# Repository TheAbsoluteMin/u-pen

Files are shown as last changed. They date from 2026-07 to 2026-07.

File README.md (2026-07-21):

# uPen

PCB_1
Case1

uPen is a WiFi-enabled smart pen that records handwritten math equations and solves them.

## Inspiration

Initially, uPen was named Insta-Form, and it would have served as an alternative for Photomath. With its own camera, it would have captured images of math problems during engineering work and then solve them instantly in order to provide a seamless experience when working with mathematical models, physics, or measurement calculations. Before, I would personally spend a lot of time writing out equations and models by hand or on a calculator. Now, uPen seeks to increase productivity and efficiency by bypassing the precious time required to find answers manually. As I have worked extensively on uPen's design and creation, I have changed its physical hardware for it to be more intuitive to use. Instead of taking pictures with a camera, users can write naturally with uPen, and it will still be able to carry out its original and intended purpose of delivering quick math answers at users' convenience!

## How it works

pageONE



## Firmware Upload Instructions

Use Arduino IDE to upload the C++ code to the uPen board (NanoS3 ESP32-S3).

## Battery Wiring Instructions

When you wire the battery with the 28 AWG wire:
1. Solder the NEGATIVE battery wire to the B- pad of the Li-ion BMS Battery Protection.
2. Solder a wire between the P- pad of the Li-ion BMS Battery Protection and the P- testpoint on the PCB.
3. Solder the POSITIVE battery wire to the RawBAT+ testpoint on the PCB.
4. Solder a wire between the B+ testpoint on the PCB to the B+ pad of the Li-ion BMS Battery Protection.
5. Solder a wire between the P+ pad of the Li-ion BMS Battery Protection and the P+ testpoint on the PCB.

## Features

* Uses compact yet powerful dual core ESP32 in the NanoS3 board
* LSM6DSV16X IMU 6-axis sensor fusion
* SDS001R tip switch for fast detection of writing state
* Small but powerful E-Flite 1S 3.7V 150mAh 45C LiPo battery
* External Li-ion BMS battery protection board
* Strong dipole 2.4GHz RX antenna
* Smart power states
* USB-C port for charging and coding
* USBLC6-2SC6 ESD protection
* Low battery alert at 15% battery
* Lightweight wireless data streaming to a base station ESP32 via ESP-NOW
* Dual I2C buses for fast data processing

## Full BOM

> [Full CSV](https://github.com/TheAbsoluteMin/u-pen/blob/main/fabrication/uPen_Full_Parts_BOM_7-21-2026.csv)

* [uPen PCB by JLCPCB](https://github.com/TheAbsoluteMin/u-pen/tree/main/fabrication)
* [NanoS3](https://www.mouser.com/en/ProductDetail/Unexpected-Maker/NS3-01?qs=Z%252BL2brAPG1JKEi5QQZzXXw%3D%3D)
* [E-Flite 1S 3.7V 150mAh 45C LiPo Battery](https://vortexhobbies.com/flite-150mah-37v-45c-lipo-battery-eflb1501s45-p-98338.html)
* [Conn_01x04 Header Pin](https://www.aliexpress.us/item/3256808220037580.html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)
* [0.91 Inch OLED Module](https://www.aliexpress.us/item/3256806851980220.html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)
* [2.4GHz FPC Antenna](https://www.aliexpress.us/item/3256806439437721.html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)
* [Li-ion BMS Battery Protection](https://www.aliexpress.us/item/3256811824864401.html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)
* [Micro JST PH 1.25 2 PIN Male Plug Connector](https://www.aliexpress.us/item/3256806436736526.html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)
* [28 AWG Wire](https://www.aliexpress.us/item/3256801404161291.html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)
* [ESP32-S3](https://www.aliexpress.us/item/3256807155434553.html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)
* [USB-C Charging Cable](https://www.aliexpress.us/item/3256807113016818.html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)
* [Kapton Tape](https://www.aliexpress.us/item/3256810334039048.html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)
* [Foam Tape](https://www.aliexpress.us/item/3256808548405172.html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)
* [uPen 3D Printed Parts](https://github.com/TheAbsoluteMin/u-pen/tree/main/3D_Models)

## Credits

* Thank you to Hack Club for the opportunity and (hopefully) funding of uPen's creation!

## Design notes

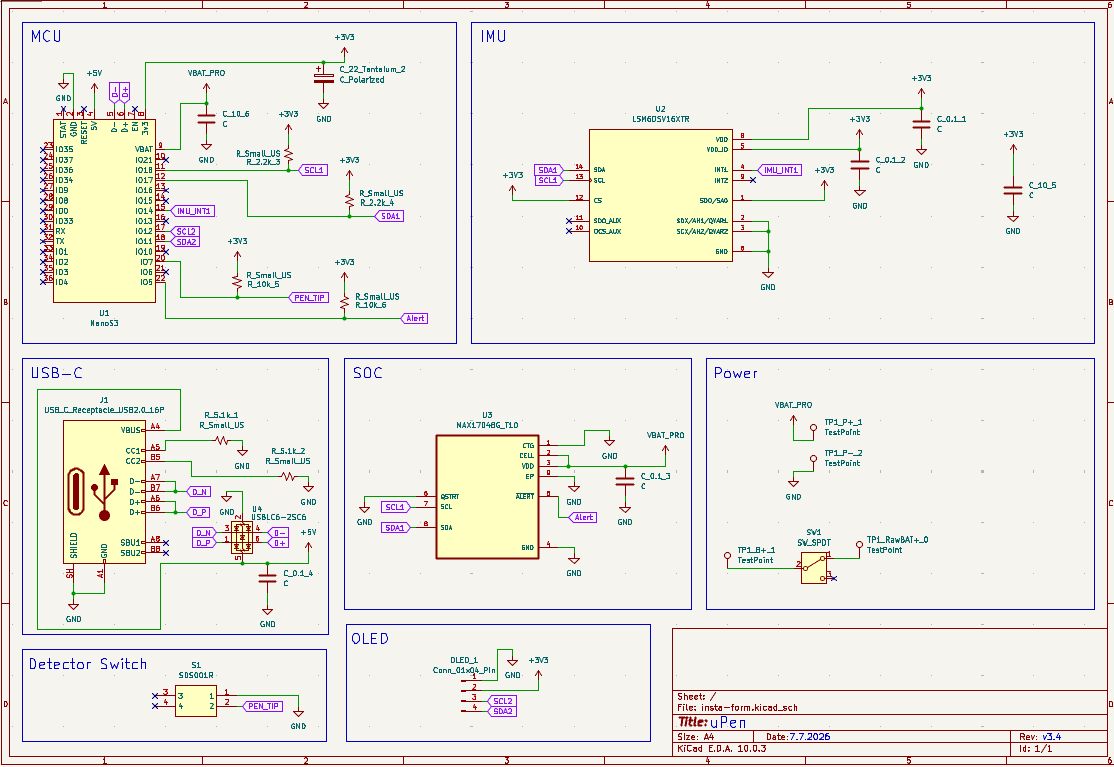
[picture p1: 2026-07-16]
assets/schematics.png

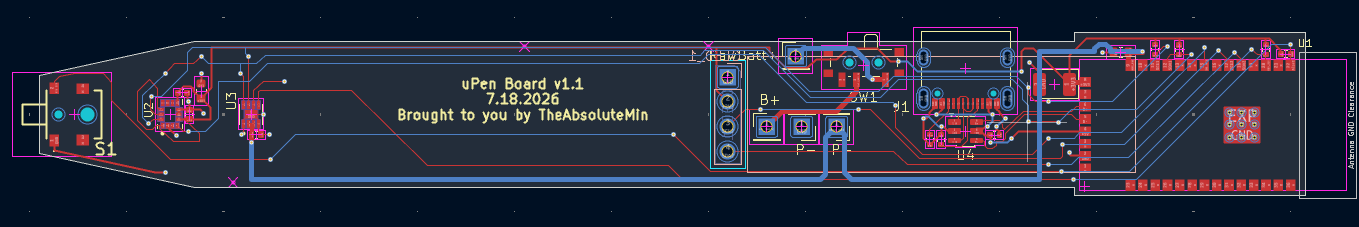
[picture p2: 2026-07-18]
assets/PCB_2.png

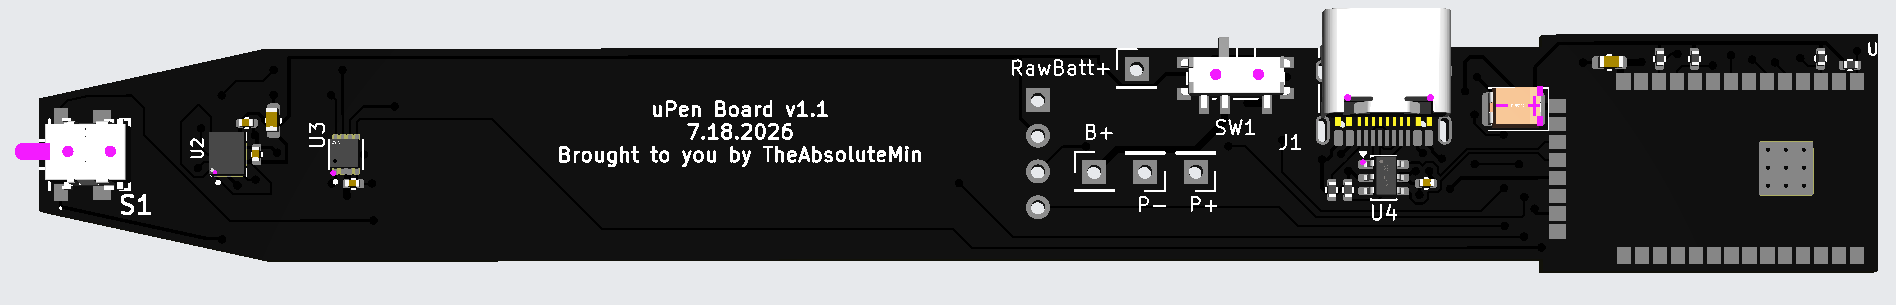
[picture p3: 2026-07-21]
assets/PCB_3.png

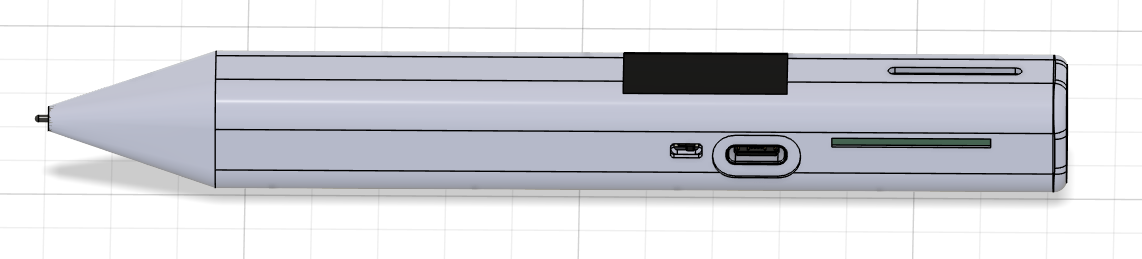
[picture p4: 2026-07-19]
assets/Case1.png

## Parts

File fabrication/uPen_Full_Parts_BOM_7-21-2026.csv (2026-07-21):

Reference | Qty | Value | DNP | Exclude from BOM | Exclude from Board | Footprint | Datasheet | Purchase Link
C_0.1_1,C_0.1_2,C_0.1_3,C_0.1_4 | 4 | C |  |  |  | Capacitor_SMD:C_0402_1005Metric |  | https://jlcpcb.com/partdetail/1877-CL05B104KO5NNNC/C1525
C_10_5,C_10_6 | 2 | C |  |  |  | Capacitor_SMD:C_0603_1608Metric |  | https://jlcpcb.com/partdetail/97651-CL10A106MA8NRNC/C96446
C_22_Tantalum_2 | 1 | C_Polarized |  |  |  | Capacitor_Tantalum_SMD:CP_EIA-3528-12_Kemet-T |  | https://jlcpcb.com/partdetail/151697-CA45_B_16V_22uFM/C140371
J1 | 1 | USB_C_Receptacle_USB2.0_16P |  |  |  | Connector_USB:USB_C_Receptacle_XKB_U262-16XN-4BVC11 | https://www.usb.org/sites/default/files/documents/usb_type-c.zip | https://jlcpcb.com/partdetail/XKBConnection-U262_161N4BVC11/C319148
S1 | 1 | SDS001R |  |  |  | KiCad:SDS001R |  | https://jlcpcb.com/partdetail/CK-SDS001R/C221963
SW1 | 1 | SW_SPDT |  |  |  | Button_Switch_SMD:SW_SPDT_PCM12 |  | https://jlcpcb.com/partdetail/CK-PCM12SMTR/C221841
TP1_B+_1,TP1_P+_1,TP1_P-_2,TP1_RawBAT+_0 | 4 | TestPoint |  |  |  | Connector_PinHeader_2.54mm:PinHeader_1x01_P2.54mm_Vertical
U2 | 1 | LSM6DSV16XTR |  |  |  | LSM6DSV16XTR (1):XDCR_LSM6DSV16XTR |  | https://jlcpcb.com/partdetail/STMicroelectronics-LSM6DSV16XTR/C5267406
U3 | 1 | MAX17048G_T10 |  |  |  | MAX17048G_T10 (1):SON50P200X200X80-9N |  | https://jlcpcb.com/partdetail/2777647-MAX17048GT10/C2682616
U4 | 1 | USBLC6-2SC6 |  |  |  | Package_TO_SOT_SMD:SOT-23-6 | https://www.st.com/resource/en/datasheet/usblc6-2.pdf | https://jlcpcb.com/partdetail/STMicroelectronics-USBLC62SC6/C7519
R_2.2k_3,R_2.2k_4 | 2 | R_Small_US |  |  |  | Resistor_SMD:R_0402_1005Metric |  | https://jlcpcb.com/partdetail/26622-0402WGF2201TCE/C25879
R_5.1k_1,R_5.1k_2 | 2 | R_Small_US |  |  |  | Resistor_SMD:R_0402_1005Metric |  | https://jlcpcb.com/partdetail/26648-0402WGF5101TCE/C25905
R_10k_5,R_10k_6 | 2 | R_Small_US |  |  |  | Resistor_SMD:R_0402_1005Metric |  | https://jlcpcb.com/partdetail/C25744
U1 | 1 | NanoS3 |  |  |  | footprints:NanoS3 |  | https://www.mouser.com/en/ProductDetail/Unexpected-Maker/NS3-01?qs=Z%252BL2brAPG1JKEi5QQZzXXw%3D%3D
Battery | 1 | E-Flite 1S 3.7V 150mAh 45C LiPo Battery |  |  |  |  |  | https://vortexhobbies.com/flite-150mah-37v-45c-lipo-battery-eflb1501s45-p-98338.html
OLED_1 | 1 | Conn_01x04_Pin |  |  |  | Connector_PinHeader_2.54mm:PinHeader_1x04_P2.54mm_Vertical |  | https://www.aliexpress.us/item/3256808220037580.html?curPageLogUid=PXPTKfBsdP5c
0.91 Inch OLED Module | 1 | 0.91 Inch OLED Module |  |  |  |  |  | https://www.aliexpress.us/item/3256806851980220.html?curPageLogUid=RrOXh1C9buab
WiFi Antenna | 1 | 2.4GHz FPC Antenna |  |  |  |  |  | https://www.aliexpress.us/item/3256806439437721.html?curPageLogUid=V6VchDGRSSNJ
Li-ion BMS Battery Protection | 1 | Li-ion BMS Battery Protection |  |  |  |  |  | https://www.aliexpress.us/item/3256811824864401.html?curPageLogUid=nS01XMH72dio
Micro JST PH 1.25 2 PIN Male Plug Connector | 1 | Micro JST PH 1.25 2 PIN Male Plug Connector |  |  |  |  |  | https://www.aliexpress.us/item/3256806436736526.html?curPageLogUid=qEtVOm34dcfy
28 AWG Wire | 1 | 28 AWG Wire |  |  |  |  |  | https://www.aliexpress.us/item/3256801404161291.html?curPageLogUid=sPUHwTLGPE0E
Base Station ESP32 | 1 | ESP32-S3 |  |  |  |  |  | https://www.aliexpress.us/item/3256807155434553.html?curPageLogUid=kWQVgJs1i7pD
USB-C Charging Cable | 1 | USB-C Charging Cable |  |  |  |  |  | https://www.aliexpress.us/item/3256807113016818.html?curPageLogUid=M8g1Yn1VT4Vm
Kapton Tape | 1 | Kapton Tape |  |  |  |  |  | https://www.aliexpress.us/item/3256810334039048.html?mp=1
Foam Tape | 1 | Foam Tape |  |  |  |  |  | https://www.aliexpress.us/item/3256808548405172.html?mp=1
uPen PCB Board | 1 | uPen PCB Board |  |  |  |  |  | https://github.com/TheAbsoluteMin/u-pen/blob/main/fabrication/Gerber_Files.zip
uPen 3D Printed Top Case | 1 | uPen 3D Printed Top Case |  |  |  |  |  | https://github.com/TheAbsoluteMin/u-pen/blob/main/3D_Models/uPen_Top_Pen_Case_PRINT.stl
uPen 3D Printed Bottom Case | 1 | uPen 3D Printed Bottom Case |  |  |  |  |  | https://github.com/TheAbsoluteMin/u-pen/blob/main/3D_Models/uPen_Bottom_Pen_Case_PRINT.stl
uPen 3D Printed Tip Extension | 1 | uPen 3D Printed Tip Extension |  |  |  |  |  | https://github.com/TheAbsoluteMin/u-pen/blob/main/3D_Models/uPen_Pen_Tip_Extension_PRINT.stl

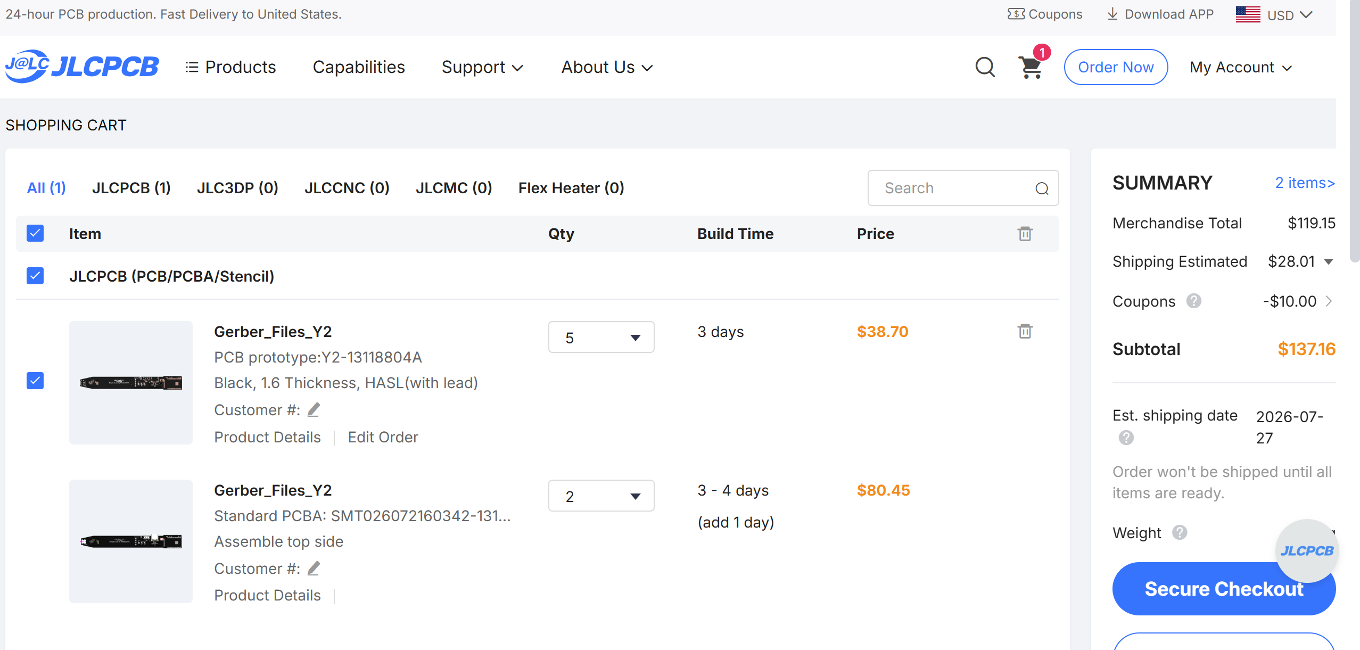
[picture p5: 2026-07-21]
fabrication/JLCPCB/JLCPCB_Cost.png

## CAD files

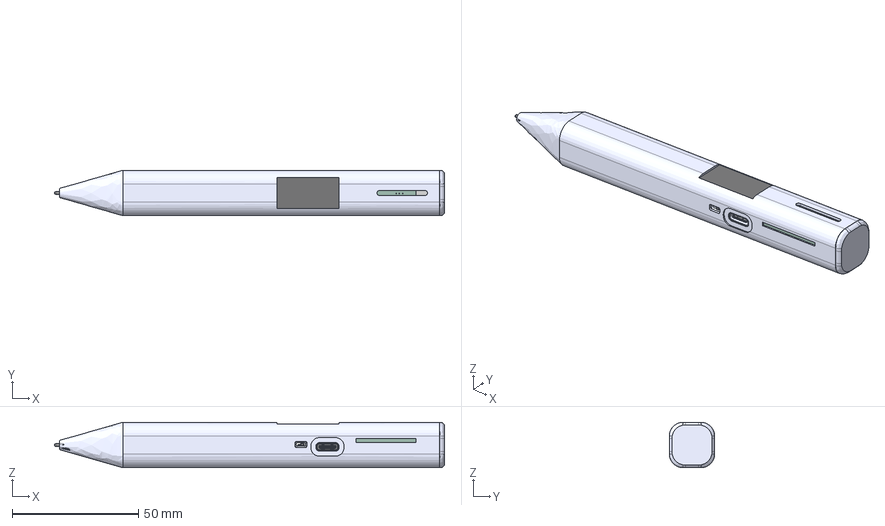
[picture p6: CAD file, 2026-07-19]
3D_Models/uPen_Completed_Model.step
154.3 x 18.0 x 18.0 mm
USB-C
SDS001R_PART1_1
SDS001R_PART2_3
SDS001R_PART2_2
SOT-23-6 (2)
C_0402_1005Metric (2) x 4
R_0402_1005Metric (2) x 6
CP_EIA_3528_12_Kemet_T (1)
Fusion_sp (1)
C_0603_1608Metric (2) x 2
TopEXTpenTip
u-pen_PCB

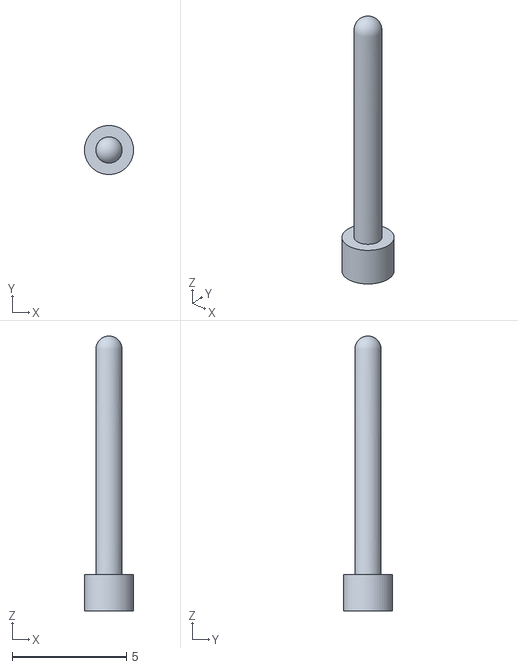
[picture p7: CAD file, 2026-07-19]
3D_Models/uPen_Pen_Tip_Extension_PRINT.stl
2.15 x 2.15 x 12.0

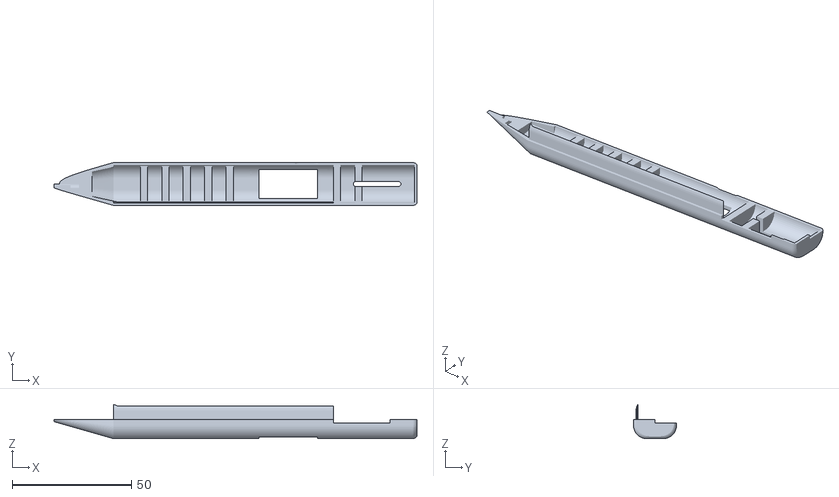
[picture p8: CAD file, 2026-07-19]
3D_Models/uPen_Top_Pen_Case_PRINT.stl
152.3 x 18.0 x 14.4

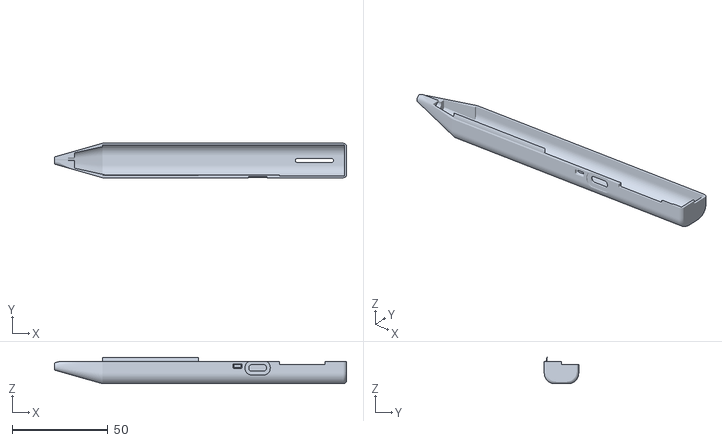
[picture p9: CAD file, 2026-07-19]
3D_Models/uPen_Bottom_Pen_Case_PRINT.stl
152.3 x 18.0 x 13.8

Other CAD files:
3D_Models/uPen_Pen_Tip_Extension.step
3D_Models/uPen_Bottom_Pen_Case.step
3D_Models/uPen_Top_Pen_Case.step

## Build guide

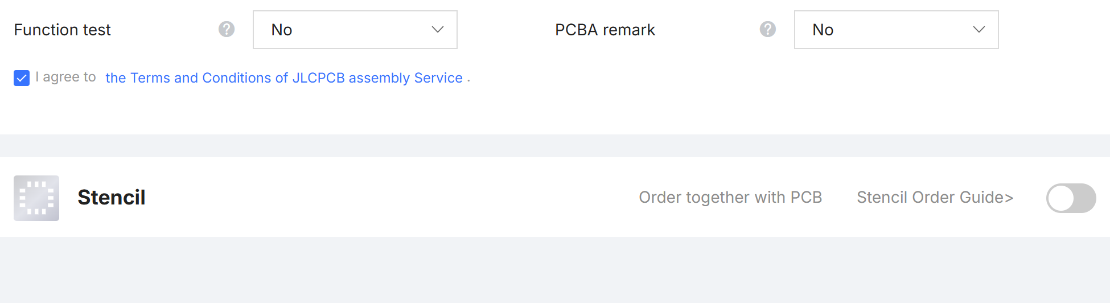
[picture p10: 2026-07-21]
fabrication/JLCPCB/JLCPCB_Settings_8.png

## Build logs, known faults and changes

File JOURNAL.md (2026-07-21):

---
title: "uPen"
author: "TheAbsoluteMin"
description: "A WiFi-enabled smart pen that records handwritten math equations and solves them."
created_at: "2026-06-21"
---

# uPen Development Log

## Log 1: June 21, 2026 - Schematics - 2 hours
Timelapse <a href="https://lapse.hackclub.com/timelapse/9_8VnrNF68hq">link</a>.

### Inspiration:
The core inspiration behind Insta-Form (now renamed as uPen) was to bridge the gap between traditional handwriting and instant digital problem-solving. While apps like Photomath exist on smartphones, switching back and forth between a screen and scratch paper disrupts the natural flow of learning and checking math work. I wanted to build a seamless quick tool that lets students or engineers keep their pen to paper while getting instant feedback.

Thus, I am excited to share the first log for Insta-Form (uPen), a smart pencil designed to instantly solve math problems using an onboard camera and Wi-Fi. I finished the first version of the hardware schematics, which is controlled by the ESP32-S3-MINI-1 microcontroller. The pencil integrates lithium battery charging via a TP4056, a USB-C interface for power, a dedicated display, and a camera.



### Struggles:
Designing a schematic with a camera, an OLED screen, and a power management system into a pencil-thin form factor came with major routing and hardware hurdles. Selecting the ESP32-S3 module was crucial for its native camera support and compact footprint, but mapping out all the connections for all the components was surprisingly difficult! I had to figure out how to wire the resistors, diodes, and capacitors in order to protect my project from frying!

### Future work:
I will review my schematics again and then, I can begin the complex design and routing of the PCB. I know it will be a challenge to fit everything in such a small board!

---

## Log 2: June 30, 2026 - Schematics Revision - 2 hours

After doing some further research into camera modules, I realized that using a camera for such close distances would not work easily. Furthermore, I would need precise lighting and a way to preview camera snapshots later on. All of these complications pushed me to revise how I would build uPen. I came across this Inertial Measurement Unit (IMU) module, and I realized that I could track and replicate the actual handwriting movements instead of using a camera to capture math problems and send them through an API to retrieve an answer. This means I would redo my entire schematic!!!



However, the IMU module presents a challenge when double integrating the acceleration values to get position coordinates of each handwritten character. It loses accuracy and precision as it continues to integrate over time due to sensor noise, meaning the plotted position points of a handwritten sentence or equation could be easily warped and a recorded position coordinate could be a foot away than the actual position!

With some further research, I found that the Time of Flight sensor could be utilized to detect when the hand and pen is lifted to move and right the next character or sentence.



With this, I would be able to send zero velocity updates (ZUPTs) in the code in order to force the velocity to be zero, which would reset integration drift errors.

I was happy to find out that the SEEED Studio XIAO ESP32S3 integrated both charging and WiFi, which would make my routing simple! Furthermore, since both the OLED, IMU module, and Time of Flight sensor all run on I2C communication, I was able to daisy chain all of these, saving me much time.

I did not use KiCad to draw the schematics this time as A PCB would have been too large to fit into a small form factor pen shape, so I used Canva. Here is what I started with:

Screenshot 2026-06-30 3 29 13 PM

and this is what I ended with:

uPen Circuit

### Future work:
I am hoping to make a tiny PCB for the back of the MCU and central routing next time, and I hope to begin working on designing how everything will fit into a 3D printed case!

---

## Log 3: July 1, 2026 - CAD Attempt - 3.4 hours

Timelapse link: https://lapse.hackclub.com/timelapse/dnVF-_9PWZdE.

Today, I worked on my schematic a bit more, optimizing the wiring and some parts. I went through small revisions.
uPen Circuitv2 1

I had to split up the I2C lines instead of daisy chaining everything. The OLED would have been extremely noisy, messing up the fast data collection of the IMU and Time of Flight modules. I also came up with a plan on how the pen would work. After the pen collects handwriting data from the IMU, it would convert the data into x and y coordinates and plot them into an image. This image of a math equation would be sent over the wifi to a math solver API, which would return a short answer to be displayed on the OLED. In order to do this, without burdening the pen's microcontroller, I thought about sending the data to a Raspberry Pi Pico 2 W, which would handle the heavy communication with an API.

uPen Circuitv2 2

After that, I began to work on the CAD design for the pen case. I first modeled the sizes for each part and placed them around a real pen footprint as I was hoping to integrate a real pen for writing while the smart pen features solve the equation in real time. However, I came across critical measurement problems.



When I began to cover the parts in a cylinder case, I realized that everything would have to fit in a 38mm diameter tube! I was aiming for a 20mm diameter and clearly, everything would not fit cleanly...



### Future work:
I am going to have to replan my materials in order to figure out how to fit everything in a thinner form factor.

---

## Log 4: July 2, 2026 - Intense Planning - 2 hours

With some research, I found an interesting microcontroller board that featured an ESP32-S3 while maintaining a small form factor of 28 by 11mm!



This gave me a lot of hope for making a pen that would fit a 20mm diameter case! The pen also featured a vast storage for holding IMU data and onboard charging.



Later, I realized that it would be easier to fit a small form factor by routing bare chips. With this, I planned to use the powerful LSM6DSV16X IMU chip with a MAX17048 chip to more accurately measure battery percentage rather than relying on a questionable voltage divider. 



It also took me forever to find a great battery that would handle power hungry Wifi transmissions while still maintaining a small form factor. I ended up with this powerful E-flite 3.7V 150mAh 1S 45C LiPo Battery!



Since I decided that housing a full pen inside the case would take up so much precious space, I got rid of it. It would pivot my project to a invisible ink or air pen, and this allowed me to drop the Time of Flight module for a SDS001R detector switch that would be placed at the tip.



Moreover, I had to rework how the pen would function! Since the user would be writing on paper without seeing the ink mark the paper, I plan to have the OLED screen display each handwritten stroke as a preview of the math equation written. Instead of using standard power hungry Wifi transmissions, I decided to use the fast ESP-NOW function with another ESP32 microcontroller in order to handle data transmission. The other ESP32 would be able to process the data with more power as it is not limited to a small battery.

### Future work:
With this new pen vision, I hope to design a schematic that would house all the pen's components in a super small PCB!

---

## Log 5: July 3, 2026 - Schematics Again! - 2 hours

Timelapse link: https://lapse.hackclub.com/timelapse/iF6mR7ldbXd7.

I honestly cannot believe that I am remaking the schematics for this project for the third time! This project has gone through major design revisions, and I hope that this one will actually work! I had to be careful wiring the connections as I had to handle the an external PCM circuit and a battery safety switch in order to prevent battery drain whenever I do not use the pen for long periods of time. I had some problems finding the exact footprint and symbols for each chip, especially the SDS001R detector switch as it is a niche part. However, with some time I was able to create a rough schematic that will need some more fine tuning.



### Future work:
After verifying my schematic with official wiring schematics for each specialized chip, I will work to ensure that my board is ready to route in the PCB editor!

---

##  Log 6: July 4, 2026 - Schematics Clean Up - 1 hour

Timelapse link: https://lapse.hackclub.com/timelapse/JP0mHgVsAJM-.

I spent a good hour organizing the schematics while following datasheet recommendations. The schematic is much more clearer, especially considering where each capacitor goes on the LSM6DSV16X (IMU) and MAX17048 fuel gauge chips! 

I was reading through Macondo Docs and I found this interesting tip:



Thus, I decided to follow the tip and use the correct symbols for power and GND flags, having power flags point up while GND flags point down. I have to admit it makes the schematics a lot more cleaner than how I had originally done them in the past.



### Future work:
I hope to finally begin working on the PCB design next time!

---

##  Log 7: July 5, 2026 - Start of PCB - 1.5 hours

Timelapse link: https://lapse.hackclub.com/timelapse/LVc4ahCd2COp.

After calculating where all the components would go, I realized that the NanoS3 microcontroller footprint was bigger than I had expected. With this, I decided to shift all the used pins to one side so that I could maximize space for routing while keeping everything in a 15mm width board.



Honestly, it was difficult to figure out how I would organize each part as I did not want to put the microcontroller at the end as the antenna would make the pen extra long. However, I also did not want to put the microcontroller and antenna near the tip of the pen as that would force the antenna to be near electronics...



It took me quite some time to make some compromises with placements, and I am still rethinking them...

### Future work:
Tomorrow, I really hope to actually start working on routing the PCB.

---

##  Log 8: July 6, 2026 - Major PCB Work - 7.5 hours

Timelapse link: https://lapse.hackclub.com/timelapse/swXfEaVnoNOx.

Today, I spent a bit too much time finalizing the entire PCB layout and working on routing all the connections. This was not easy as it was also my first time routing a bare USB-C receptacle, and I quickly found it to be extremely difficult!

I began by adding the ESD USB-C protection chip USBLC6-2SC6 into my schematic.



When I began routing using KiCad's differential routing tool, it refused to connect to the ESD chip as the Data lines were reversed in the footprint layout! 



I tried numerous ways to connect the lines, and they were all far from equal in length.




After many attempts, I settled on a somewhat symmetrical connection style with vias, and I almost got the data lines to be equal in length. Thankfully, wiring all the other components were relatively straightforward. Yet, it was still a time-consuming task.



Even after all that hard work, KiCad came up with many errors and I realized I did not route the GND pad thats stuck in the middle of the ESD chip with almost no space for more routing!



### Future work:
After much rest, I must figure out how to optimize this PCB routing and solve all those Design Rules Checker errors...

---

##  Log 9: July 7, 2026 - PCB Version 2! - 4 hours

Timelapse link: https://lapse.hackclub.com/timelapse/U-yj73YHo-n-.

I was not expecting to redo the entire PCB routing again from scratch... However, after some thinking and looking at the messy routing I had done, I was set on fixing it all. Instead of simply routing wires on four different layers wherever I wanted, I decided to come up with a plan on how I would handle routing on each layer. 

I decided to place all power and data lines on the first and fourth layer while the second and third layers would be ground planes. Since most of the SMD parts needed to be on the top layer of the PCB, I needed a ground plane directly underneath them, especially for the USB-C receptacle. However, since I had many data lines, including two sets of I2C lines, I wanted to have a ground plane to separate the data lines on different layers to prevent crosstalk. With this, I set a global clearance rule of 0.25mm from all vias and routing, which helped me to freely route while letting KiCad handle the spacing.

I honestly found this PCB much easier to route than before, but I realized that I may have made too many holes in the ground plane...




A key difficulty that limited how I could wire was that since the NanoS3 had exposed vias on its bottom layer, I wanted to avoid routing anything inside the microcontroller footprint. This meant I had to squeeze in vias for each pin.



Anyhow, this is what the entire PCB looks like as of right now:



### Future work:
Next time, I look forward to checking over the PCB with Design Rules Checker again and starting the CAD for the pen case design!

---

##  Log 10: July 8, 2026 - CAD Attempt 2 - 1.5 hours

Timelapse link: https://lapse.hackclub.com/timelapse/-Hel6EKzSH4P.

I did not think I could have so many errors to solve!



I went through each of them and found out that most of them were flagging the clearances of the footprint pads of the SMD parts. Apparently, I had set the default clearance to 0.25mm which was too big for the SMD parts...

As I began working on the CAD design, I chose a rounded square prism shape for the case because I wanted to do somthing different than a generic cylinder. Also, the OLED screen would look much more natural with the rounded square prism.



While it was great to reference the STEP file of my PCB, I quickly found that the switch part was too wide, meaning I would have to later extend the pen tip...




### Future work:
I will make some adjustments to the CAD design and work on creating holes and supports for the components on the PCB board.

---

##  Log 11: July 9, 2026 - Heavy CAD Work - 3.5 hours

Timelapse link: https://lapse.hackclub.com/timelapse/df8S33CcSg0K.

Upon realizing that the USB-C receptacle was supposed to stick outside the PCB a bit so it would naturally fit in the CAD case, I had to adjust move its footprint in the PCB.



I spent a lot of time figuring out how to create supports for the floating PCB in the hollow case, and I initially wanted to use the rib function in Autodesk Fusion. With some time, I realized it would be easier to do so with the combine, extrude, and cut functions by using the case and PCB to carve out supports.





### Future work:
I am hoping to finish the CAD case design tomorrow!

---

##  Log 12: July 10, 2026 - CAD Completion - 2.5 hours

Timelapse link: https://lapse.hackclub.com/timelapse/YAtuVmnhOys9.

I could not believe my eyes when I reopened Autodesk Fusion today. It had signed me out automatically with an error, so I refreshed the software and logged in again. However, upon opening my project file, I realized that it had not saved any work from yesterday! Thus, after some extremely deep breaths, I spent my time redoing the supports and holes for uPen's case. I even included holes for the NanoS3 so that heat could escape, which will be crucial when the ESP32 chip runs WiFi transmissions. 





Finally, with some pretty coloring, I put all the CAD parts together into a final model!




### Future work:
I will begin working on exporting all my project files for a design submission on Hack Club for funding!

---

##  Log 13: July 12, 2026 - Coding - 3 hours

In my mind, the code for uPen was not too hard... until I realized how many parts I had to integrate into the code, including the fuel gauge, IMU, OLED display, interupts, dual I2C lines, ESP-Now, and data packet tracking! In order to keep everything organized, I had to utilize pen states: drawing, solving, and charging.



Since I also realized that I would be sending data packets of IMU X and Y coordinates of handwritten motions every 150ms, I would need to keep those WiFi bursts as minimal as possible, so the battery and NanoS3 would not get too hot.



I also had to come up with a code system, so I could determine whether a data packet represented the pen writing or moving mid-air. The variable point.is_pressed is 1 when the user is currently writing, 0 when the pen is mid-air, and the final 255 when a 5 second inactivity triggers the solving state.



### Future work:
Later, I will begin compiling all my project files for uPen to put them into GitHub.

---

##  Log 14: July 15, 2026 - uPen GitHub Work - 1 hour

After downloading the many files for my project, including the source files for the Autodesk Fusion CAD files and KiCad PCB and Schematic files, I began to work on the GitHub README. Specifically, I created a colorful guide on Canva for demonstrating how to use uPen and explaining how it works!

pageONE



### Future work:
I hope to finally finish the GitHub work for uPen soon!

---

##  Log 15: July 16, 2026 - uPen GitHub Work Again! - 1 hour

Today, I realized the great amount of work needed to put everything together into a nice GitHub repository! It took me a while to recall all the features of uPen, so I could put it all into the README.md.



I ran into many problems with uploading files as many of them somehow lost their file code!



Another difficult task was gathering all the parts needed in the BOM and finding their respective purchase links! This required a lot of time scrolling through product listings...



### Future work:
Tomorrow, I will find the total value of all the items needed to build uPen, so I can finally submit the design to Hack Club!

---

## Log 16: July 21, 2026 - Project Design Submission!

After many, many hours working, redesigning, and adjusting the design for uPen, I have finally finished! I cannot wait to actually put this all together physically, and I began to 3D print the CAD case files!





Until next time,
TheAbsoluteMin

---

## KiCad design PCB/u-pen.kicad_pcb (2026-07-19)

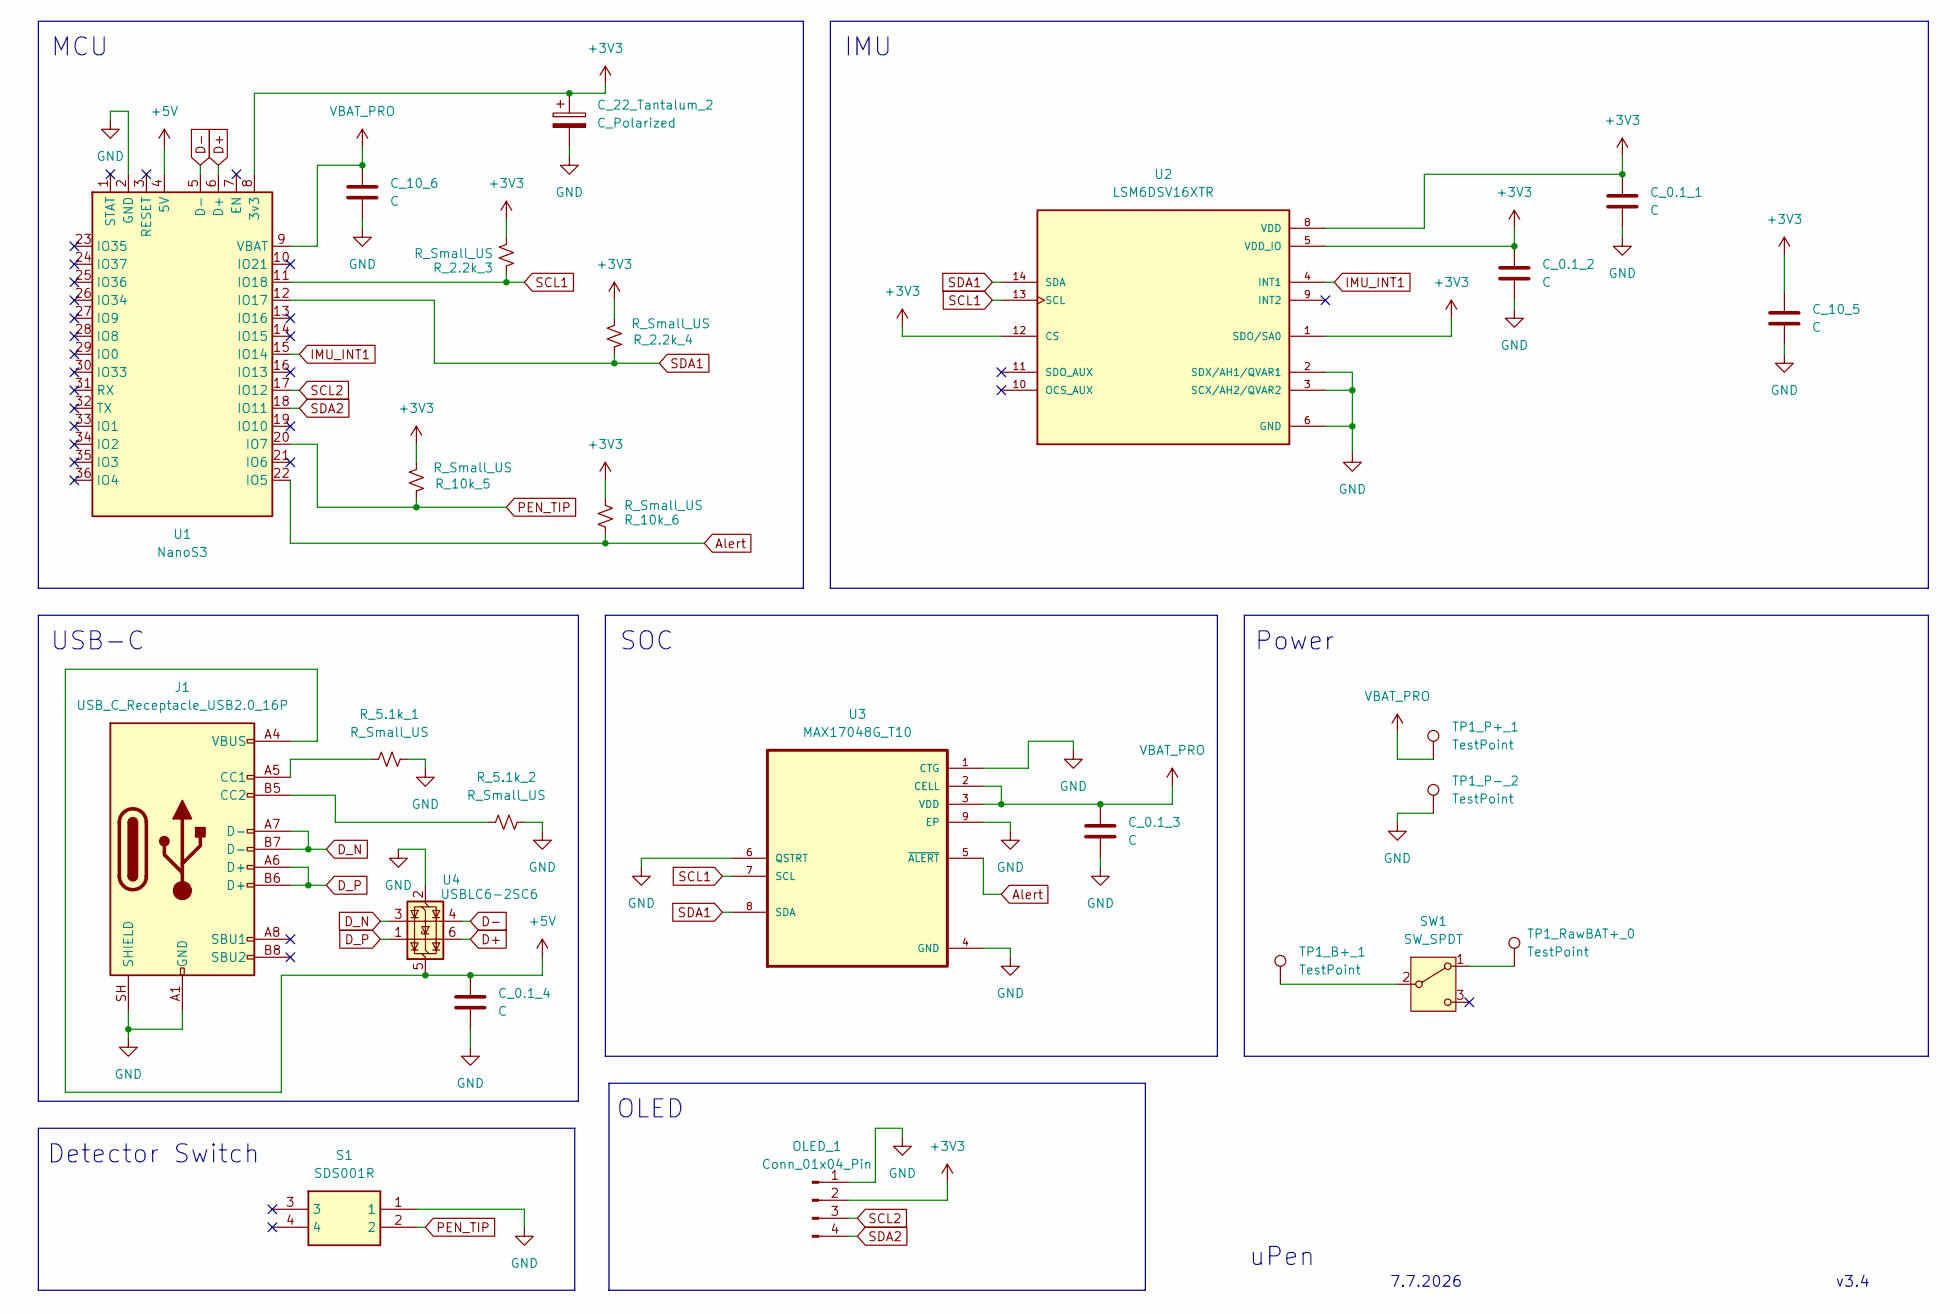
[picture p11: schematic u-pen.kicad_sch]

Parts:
C_0.1_1, C_0.1_2, C_0.1_3, C_0.1_4: C; C_0402_1005Metric
C_10_5, C_10_6: C; C_0603_1608Metric
C_22_Tantalum_2: C_Polarized; CP_EIA-3528-12_Kemet-T
J1: USB_C_Receptacle_USB2.0_16P; USB_C_Receptacle_XKB_U262-16XN-4BVC11
OLED_1: Conn_01x04_Pin; PinHeader_1x04_P2.54mm_Vertical
R_2.2k_3, R_2.2k_4, R_5.1k_1, R_5.1k_2, R_10k_5, R_10k_6: R_Small_US; R_0402_1005Metric
S1: SDS001R; Manufacturer_Part_Number SDS001R
SW1: SW_SPDT; SW_SPDT_PCM12
TP1_B+_1, TP1_P+_1, TP1_P-_2, TP1_RawBAT+_0: TestPoint; PinHeader_1x01_P2.54mm_Vertical
U1: NanoS3
U2: LSM6DSV16XTR; XDCR_LSM6DSV16XTR; PARTREV 4
U3: MAX17048G_T10; SON50P200X200X80-9N
U4: USBLC6-2SC6; SOT-23-6

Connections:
+3V3: C_0.1_1.1, C_0.1_2.1, C_10_5.1, C_22_Tantalum_2.1, OLED_1.2, R_2.2k_3.2, R_2.2k_4.2, R_10k_5.2, R_10k_6.1, U1.8 (3v3), U2.1 (SDO/SA0), U2.5 (VDD_IO), U2.8 (VDD), U2.12 (CS)
+5V: C_0.1_4.1, J1.A4 (VBUS), J1.A9 (VBUS), J1.B4 (VBUS), J1.B9 (VBUS), U1.4 (5V), U4.5 (VBUS)
Alert: R_10k_6.2, U1.22 (IO5), U3.5 (~ALERT)
D+: U1.6 (D+), U4.6 (I/O1)
D-: U1.5 (D-), U4.4 (I/O2)
D_N: J1.A7 (D-), J1.B7 (D-), U4.3 (I/O2)
D_P: J1.A6 (D+), J1.B6 (D+), U4.1 (I/O1)
GND: C_0.1_1.2, C_0.1_2.2, C_0.1_3.2, C_0.1_4.2, C_10_5.2, C_10_6.2, C_22_Tantalum_2.2, J1.A1 (GND), J1.A12 (GND), J1.B1 (GND), J1.B12 (GND), J1.SH (SHIELD), OLED_1.1, R_5.1k_1.1, R_5.1k_2.1, S1.1, TP1_P-_2.1 (1_1), U1.2 (GND), U1.EXP, U2.2 (SDX/AH1/QVAR1), U2.3 (SCX/AH2/QVAR2), U2.6 (GND), U2.7 (GND), U3.1 (CTG), U3.4 (GND), U3.6 (QSTRT), U3.9 (EP), U4.2 (GND)
IMU_INT1: U1.15 (IO14), U2.4 (INT1)
unnamed: J1.A5 (CC1), R_5.1k_1.2
unnamed: J1.B5 (CC2), R_5.1k_2.2
unnamed: SW1.1 (A), TP1_RawBAT+_0.1 (1_1)
unnamed: SW1.2 (B), TP1_B+_1.1 (1_1)
PEN_TIP: R_10k_5.1, S1.2, U1.20 (IO7)
SCL1: R_2.2k_3.1, U1.11 (IO18), U2.13 (SCL), U3.7 (SCL)
SCL2: OLED_1.3, U1.17 (IO12)
SDA1: R_2.2k_4.1, U1.12 (IO17), U2.14 (SDA), U3.8 (SDA)
SDA2: OLED_1.4, U1.18 (IO11)
VBAT_PRO: C_0.1_3.1, C_10_6.1, TP1_P+_1.1 (1_1), U1.9 (VBAT), U3.2 (CELL), U3.3 (VDD)

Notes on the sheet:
OLED
USB-C
Detector Switch
MCU
v3.4
uPen
7.7.2026
IMU
Power
SOC

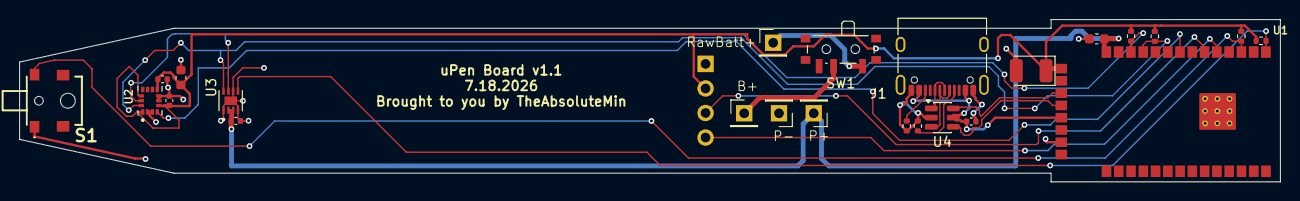
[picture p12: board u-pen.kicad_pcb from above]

Board: 4 copper layers, 130.5 x 16.8 mm, 25 parts (1 on the bottom side), 19 nets.

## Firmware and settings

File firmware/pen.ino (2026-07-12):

//main pen code

#include <Arduino.h>
#include <WiFi.h>
#include <esp_now.h>
#include <Wire.h>
#include <Adafruit_GFX.h>
#include <Adafruit_SSD1306.h>
#include <SparkFun_MAX17048_Arduino_Library.h>
#include <LSM6DSV16XSensor.h>

#define PEN_TIP_PIN 7
#define BAT_ALERT_PIN 5
#define IMU_INT1_PIN 14
#define SCREEN_WIDTH 128
#define SCREEN_HEIGHT 32
#define OLED_RESET -1

uint8_t baseStationMac[] = {0x24, 0x4C, 0xAB, 0x11, 0x22, 0x33};

//dual I2C buses
TwoWire I2C_Bus1 = TwoWire(0); // bus 1: IMU + battery gauge
TwoWire I2C_Bus2 = TwoWire(1); // bus 2: OLED display screen

LSM6DSV16XSensor IMU(&I2C_Bus1);
SFE_MAX17048 FuelGauge;
Adafruit_SSD1306 Display(SCREEN_WIDTH, SCREEN_HEIGHT, &I2C_Bus2, OLED_RESET);

//data packet structure
typedef struct {
    int16_t x_pos;
    int16_t y_pos;
    uint8_t is_pressed;
} SimplePoint;

//pen system states
enum PenSystemState { MODE_DRAWING, MODE_SOLVING, MODE_CHARGING };
PenSystemState currentSystemMode = MODE_DRAWING;

float globalX = SCREEN_WIDTH / 4; 
float globalY = SCREEN_HEIGHT / 2;

uint32_t lastTimeActive = 0;
uint32_t lastNetworkTxTime = 0;

volatile bool lowBatteryHardwareFlag = false;
volatile bool imuDataReadyHardwareFlag = false;

void IRAM_ATTR onBatteryAlertInterrupt() {
    lowBatteryHardwareFlag = true; 
}

void IRAM_ATTR onImuDataReadyInterrupt() {
    imuDataReadyHardwareFlag = true;
}

//get and display API answer
void OnDataRecv(const esp_now_recv_info *recvInfo, const uint8_t *incomingData, int len) {
    Display.clearDisplay();
    Display.setCursor(0, 10);
    Display.print("Ans: ");
    Display.println((char*)incomingData);
    Display.display();
    
    currentSystemMode = MODE_DRAWING;
    lastTimeActive = millis(); 
}

void setup() {
    Serial.begin(115200);
    //pins
    pinMode(PEN_TIP_PIN, INPUT);
    pinMode(BAT_ALERT_PIN, INPUT);
    pinMode(IMU_INT1_PIN, INPUT);
    attachInterrupt(digitalPinToInterrupt(BAT_ALERT_PIN), onBatteryAlertInterrupt, FALLING);
    attachInterrupt(digitalPinToInterrupt(IMU_INT1_PIN), onImuDataReadyInterrupt, RISING);
    //I2C
    I2C_Bus1.begin(17, 18, 100000); 
    I2C_Bus2.begin(11, 12, 100000); 
    //OLED
    Display.begin(SSD1306_SWITCHCAPVCC, 0x3C);
    Display.clearDisplay();
    Display.setTextSize(1);
    Display.setTextColor(SSD1306_WHITE);
    Display.setCursor(0, 10);
    Display.println("Pen Booting...");
    Display.display();
    //fuel gauge
    FuelGauge.begin(I2C_Bus1);
    FuelGauge.setAlertThreshold(15); 
    FuelGauge.quickStart();
    //IMU 
    IMU.begin();
    IMU.Enable_6AXIS_Sensor_Fusion(); 
    IMU.Enable_X(); 
    IMU.Set_X_ODR(50.0f);
    //ESP-NOW
    WiFi.mode(WIFI_STA);
    WiFi.disconnect();
    if (esp_now_init() == ESP_OK) {
        esp_now_register_recv_cb(esp_now_recv_cb_t(OnDataRecv));
        esp_now_peer_info_t peerInfo = {};
        memcpy(peerInfo.peer_addr, baseStationMac, 6);
        peerInfo.channel = 1;
        peerInfo.encrypt = false;
        esp_now_add_peer(&peerInfo);
    }
    //timers
    lastTimeActive = millis();
    lastNetworkTxTime = millis();
}

void loop() {
    float cellVoltage = FuelGauge.getVoltage();
    if (cellVoltage > 4.22f) {
        currentSystemMode = MODE_CHARGING;
    }

    if (lowBatteryHardwareFlag) {
        Display.clearDisplay();
        Display.setCursor(0, 10);
        Display.printf("LOW BAT: %.1f%%", FuelGauge.getSOC());
        Display.display();
        delay(2000); 
        lowBatteryHardwareFlag = false; 
    }

    switch (currentSystemMode) {

        case MODE_DRAWING: {
            if (imuDataReadyHardwareFlag) {
                imuDataReadyHardwareFlag = false;

                bool tipPressed = (digitalRead(PEN_TIP_PIN) == LOW);
                
                int32_t linearAccel = {0, 0, 0};
                IMU.Get_X_Linear_Acceleration(linearAccel); 
                
                int32_t pureHandX = linearAccel[0]; 
                int32_t pureHandY = linearAccel[1]; 

                if (tipPressed) {
                    lastTimeActive = millis(); 
                    globalX += (float)pureHandX * 0.002f;
                    globalY += (float)pureHandY * 0.002f;
                } else {
                    globalX += (float)pureHandX * 0.0004f; 
                    globalY += (float)pureHandY * 0.0004f;
                }

                globalX = constrain(globalX, 0, SCREEN_WIDTH - 1);
                globalY = constrain(globalY, 0, SCREEN_HEIGHT - 1);
            }

            //concurrent data packet transmission every 150ms to base ESP32
            if (millis() - lastNetworkTxTime >= 150) {
                bool tipPressedNow = (digitalRead(PEN_TIP_PIN) == LOW);
                
                SimplePoint dataPacket;
                dataPacket.x_pos = (int16_t)globalX;
                dataPacket.y_pos = (int16_t)globalY;
                dataPacket.is_pressed = tipPressedNow ? 1 : 0;

                //automatic solver after 5 seconds of inactivity
                if (!tipPressedNow && (millis() - lastTimeActive >= 5000)) {
                    currentSystemMode = MODE_SOLVING;
                    
                    Display.clearDisplay();
                    Display.setCursor(0, 10);
                    Display.println("Solving...");
                    Display.display();

                    dataPacket.is_pressed = 255; 
                }

                esp_now_send(baseStationMac, (uint8_t*)&dataPacket, sizeof(SimplePoint));
                lastNetworkTxTime = millis(); 
            }
            break;
        }

        case MODE_SOLVING: {
            if (digitalRead(PEN_TIP_PIN) == LOW) {
                currentSystemMode = MODE_DRAWING;
                lastTimeActive = millis();
                Display.clearDisplay();
            }
            break;
        }

        case MODE_CHARGING: {
            Display.clearDisplay();
            Display.setCursor(0, 0);
            Display.printf("Charging Pen...\nVolts: %.2fV\nBattery: %.1f%%", cellVoltage, FuelGauge.getSOC());
            Display.display();
            
            delay(1000); 
            
            //check if USB charger is unplugged and LiPo battery is full
            if (cellVoltage < 4.15f) { 
                currentSystemMode = MODE_DRAWING;
                lastTimeActive = millis();
                Display.clearDisplay();
            }
            break;
        }
    }
}

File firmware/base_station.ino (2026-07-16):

//base_station code for external ESP32 to process pen packet data in real time

#include <Arduino.h>
#include <WiFi.h>
#include <esp_now.h>
#include <HTTPClient.h>

#define CANVAS_WIDTH 128
#define CANVAS_HEIGHT 32

const char* WIFI_SSID = "example_wifi_name";
const char* WIFI_PASSWORD = "example_wifi_password";
const char* AI_SOLVER_URL = "example_api_url.com";

//data packet structure
typedef struct {
    int16_t x_pos;
    int16_t y_pos;
    uint8_t is_pressed;
} SimplePoint;

uint8_t virtualCanvas[CANVAS_WIDTH][CANVAS_HEIGHT];
int16_t prevX = CANVAS_WIDTH / 4;
int16_t prevY = CANVAS_HEIGHT / 2;

//API solver function
String connectAndCallAI() {
    Serial.println("\nConnecting to Wi-Fi...");
    WiFi.begin(WIFI_SSID, WIFI_PASSWORD);
    
    uint32_t startAttemptTime = millis();
    while (WiFi.status() != WL_CONNECTED && millis() - startAttemptTime < 10000) {
        delay(500);
        Serial.print(".");
    }

    if (WiFi.status() != WL_CONNECTED) {
        Serial.println("WiFi Connection Failed");
        return "Big Error";
    }
    Serial.println("\nConnected!");

    HTTPClient http;
    http.begin(AI_SOLVER_URL);
    http.addHeader("Content-Type", "application/json");

    String jsonPayload = "{\"width\":128,\"height\":32,\"strokes\":[";
    bool firstPoint = true;

    for (int x = 0; x < CANVAS_WIDTH; x++) {
        for (int y = 0; y < CANVAS_HEIGHT; y++) {
            if (virtualCanvas[x][y] == 1) {
                if (!firstPoint) jsonPayload += ",";
                jsonPayload += "{\"x\":" + String(x) + ",\"y\":" + String(y) + "}";
                firstPoint = false;
            }
        }
    }
    jsonPayload += "]}";

    int httpResponseCode = http.POST(jsonPayload);
    String resultString = "Error";

    if (httpResponseCode > 0) {
        String responseBody = http.getString();
        Serial.println("API Response: " + responseBody);
        
        resultString = responseBody;
    } else {
        Serial.printf("API HTTP POST Failure. Error Code: %d\n", httpResponseCode);
        resultString = "API Fail";
    }

    http.end();
    WiFi.disconnect(true);
    WiFi.mode(WIFI_STA);
    return resultString;
}

//get data packets
void OnDataRecv(const esp_now_recv_info *recvInfo, const uint8_t *incomingData, int len) {
    if (len == sizeof(SimplePoint)) {
        SimplePoint point;
        memcpy(&point, incomingData, sizeof(SimplePoint));

        int16_t curX = point.x_pos;
        int16_t curY = point.y_pos;

        if (point.is_pressed == 1) {
            Serial.printf("Drawing line from (%d,%d) to (%d,%d)\n", prevX, prevY, curX, curY);
            virtualCanvas[constrain(curX, 0, CANVAS_WIDTH-1)][constrain(curY, 0, CANVAS_HEIGHT-1)] = 1;
            prevX = curX;
            prevY = curY;
        } 
        else if (point.is_pressed == 0) {
            Serial.printf("Hover cursor to (%d,%d)\n", curX, curY);
            prevX = curX;
            prevY = curY;
        } 
        else if (point.is_pressed == 255) {
            //ask API
            Serial.println("Complete: 5 second inactivity. Asking API...");
            String solutionAnswer = connectAndCallAI();

            char replyPayloadBuffer[32];
            memset(replyPayloadBuffer, 0, sizeof(replyPayloadBuffer));
            solutionAnswer.toCharArray(replyPayloadBuffer, sizeof(replyPayloadBuffer) - 1);

            //send back answer to pen
            esp_now_init();

            esp_now_peer_info_t penPeer = {};
            memcpy(penPeer.peer_addr, recvInfo->src_addr, 6);
            penPeer.channel = 1;
            penPeer.encrypt = false;
            
            if (!esp_now_is_peer_exist(recvInfo->src_addr)) {
                esp_now_add_peer(&penPeer);
            }

            esp_now_send(recvInfo->src_addr, (uint8_t*)replyPayloadBuffer, strlen(replyPayloadBuffer) + 1);
            Serial.printf("Response Complete: Dispatched text string '%s' to Pen.\n", replyPayloadBuffer);

            //reset
            memset(virtualCanvas, 0, sizeof(virtualCanvas));
        }
    }
}

void setup() {
    Serial.begin(115200);

    WiFi.mode(WIFI_STA);
    WiFi.disconnect();

    if (esp_now_init() == ESP_OK) {
        Serial.println("Base Station Activated. Monitoring wireless pen telemetry channels...");
        esp_now_register_recv_cb(esp_now_recv_cb_t(OnDataRecv));
    }
    
    memset(virtualCanvas, 0, sizeof(virtualCanvas));
}

void loop() {
    //nothing here!
}

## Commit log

2026-07-16 Move into PCB folder
    [insta-form.kicad_sch]
2026-07-16 Rename file
    [u-pen.kicad_pcb]
2026-07-16 Move to 3D_Models/ folder
    [uPen_V1_CAD_Case_Source_File.f3d]
2026-07-16 Move to 3D_Models folder
    [uPen_Bottom_Case.step, uPen_Full_Assembled_Model.step, uPen_Pen_Tip_Extension.step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]
2026-07-16 Add 3D_Models files
    [uPen_Bottom_Case.step, uPen_Full_Assembled_Model.step, uPen_Pen_Tip_Extension.step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]
2026-07-16 Add gerber files
2026-07-16 Add .stl CAD files
    [uPen_Bottom_Case_Print.stl, uPen_Pen_Tip_Extension_Print.stl, uPen_Top_Case_Print.stl]
2026-07-17 Add updated BOM
    [uPen_BOM_v1.csv]
2026-07-17 Update uPen_BOM_v1.csv 2
    [uPen_BOM_v1.csv]
2026-07-17 Move to fabrication folder
    [BOM.csv]
2026-07-18 Add updated files
    [u-pen.kicad_pcb]
2026-07-18 Add updated gerber files
2026-07-18 Add updated PCB pictures
2026-07-19 Add fixed CAD source file
2026-07-19 Add completed model STEP file
    [uPen_Completed_Model.step]
2026-07-19 Add top pen case STEP file
    [uPen_Top_Pen_Case.step]
2026-07-19 Add bottom pen case STEP file
    [uPen_Bottom_Pen_Case.step]
2026-07-19 Add bottom pen case STL file
    [uPen_Bottom_Pen_Case_PRINT.stl]
2026-07-19 Add top pen case STL file
    [uPen_Top_Pen_Case_PRINT.stl]
2026-07-19 Add pen tip extension STEP and STL files
    [uPen_Pen_Tip_Extension.step, uPen_Pen_Tip_Extension.stl]
2026-07-19 Add updated CAD pictures
2026-07-19 Add updated BOM file
    [uPen_BOM.csv]
2026-07-19 Add updated KiCad files
    [u-pen.kicad_pcb]
2026-07-20 Add JLCPCB BOM
    [u-pen_JLCPCB_BOM.csv]
2026-07-20 Add JLCPCB CPL file
    [JLCPCB_CPL_u-pen-top-pos.csv]
2026-07-20 Add updated CPL file
    [JLCPCB_CPL_u-pen-top-pos.csv]
2026-07-20 Add updated JLCPCB BOM file
    [JLCPCB_BOM_u-pen.csv]
2026-07-20 Add fixed JLCPCB BOM and CPL files
    [JLCPCB_BOM_u-pen.csv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]
2026-07-21 Add assembled PCB view
2026-07-21 Move to JLCPCB folder
    [JLCPCB_BOM_u-pen.csv]
2026-07-21 Add updated full BOM
    [uPen_Full_Parts_BOM_7-21-2026.csv]
2026-11-07 Add PCB STEP file v2
2026-11-07 Add PCB Source file
2026-11-10 Upload Full BOM
